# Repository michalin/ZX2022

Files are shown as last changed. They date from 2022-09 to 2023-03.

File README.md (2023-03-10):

# ZX 2022
Yet another homebuilt Z80 Computer, but this one works without any FPGAs or Microcontrollers, but components that were available at the time when the Z80 processor was state of the art. It can run historic CP/M programs like Multiplan, Wordstar and MBasic, as well as some games. This is a reminiscense to the Sinclair ZX81 computer. 
In contrast to its predecessor, the ZX2020, this one uses a 32 kilobyte EE Prom to reliably store the CP/M BDOS and BIOS. Furthermore a PS/2, or  PS/2 compatible USB keyboard can be connected. With an optional TMS99x8 based video card, a  TV or monitor can also be used. This repository contains gerber files for both the ZX2022 and the video  card. So it can now be easily replicated.

## Features
- Zilog Z80 processor @6MHz, higher clock rates might also work.
- 128 Kilobytes of static RAM, can be switched in banks of 32k
- 32 Kilobytes of EEprom
- 2 Serial UART ports 187.5 kBaud (Clock freqency/32):
  - Terminal emulation, (Putty works best)
  - File transfer. Files in a special folder on the PC show up as drive B>
- EEprom provides 15 Kilobytes of file memory (drive A>). CP/M executables are started automatically after reset or power on
- IDE (PATA) interface. Provides 4x16 Kilobyte organized as drives C>..F>
- CP/M 3.0
- 64-Pin connector for up to 6 Extension modules
- Optional graphics card with TMS99x8. 
    - 256x192 pixels and 15 colors
    - 32 Sprites (8x8, 16x16 or 32x32 upscaled)
    - NTSC (TMS9918) or PAL (TMS9928)
- Supports PS/2 or PS/2 compatible USB keyboards. New USB keyboards or wireless keyboards may NOT work.
- Now programmable in C using SDCC (Small Device C Compiler)

## To build the ZX 2022, do the following
- Wire the parts on a breadboard or prototype board according to the schematic. 
- OR: Make or order a PCB based on the gerber files `./Schematic/Mainboard/gerber-main.zip` (Recommended)
- Load the Arduino Sketch `loader/loader.ino` into an Arduino Mega
- Plug the Arduino Mega on the Bus connector, where it is marked on the silkscreen
- Connect the TxB and RxB pins of the DART with Pin 0 (TX0) and 1 (RX0) of your Arduino Mega
- Start a serial terminal emulation, for example "Putty", set 187500 Baud, 8 Bit, 1 Stopbit, no parity
- On Windows, run the tool `bin/loader.exe`. Click on "ROM Image" and select the file `CPM/rom.img`
- When a welcome message and the CP/M prompt "B>" appears on your terminal emulation, the ZX2020 is ready to use. If you have a PATA compatible hard drive connected, you need to format it under CP/M with the "mkdsk.com" tool before you can use it. Note that all data on the disk will be lost. 

## Using The Serial Disk Drive
Connect RX0 of the Arduino with TxB and TX0 with RxB of the ZX2022. 
It is not necessary to plug the Arduino into the pin header. Instead of an Arduino, a USB to serial converter may be used here as well. Select the serial port in the drop down menu and check the "Connect" check box to establish the serial connection. After a reset, the serial disk drive can be accessed as drive B>.

The folder [CPM/serdisk](./CPM/serdisk/) contains the CP/M programs in up to 16 user folders numbered from 0 to 15. If any of these files have changed, click the "Reload" Button to apply the changes. To access the files from CP/M, type `B`, followed by the user number 1-15 and a colon. For example `B5:` gives access to the files under [CPM/serdisk/5](./CPM/serdisk/5)

## Connecting a Hard Drive
IDE (PATA) hard drives can be connected through a 40-Pin connector. I recommend using a CompactFlash with a CF to IDE adapter. Best suitable are adapters that support power supply over pin 20 like this one: [https://amzn.to/3SFdIag](https://amzn.to/3SFdIag). call ´mkdsk.com´ on the serial disk drive B> to format the drive.

## The Autostart Feature
Clicking the `File` button in the loader app uploads an executable CP/M file (*.com) that is executed after each power-on or reboot. The loader app detects when there is a new version of this "autostart program" and restarts the ZX2022 with this new version. This function is particularly useful for writing new software.

## Connecting a PS/2 Keyboard
Connect a PS/2 Keyboard like shown below:

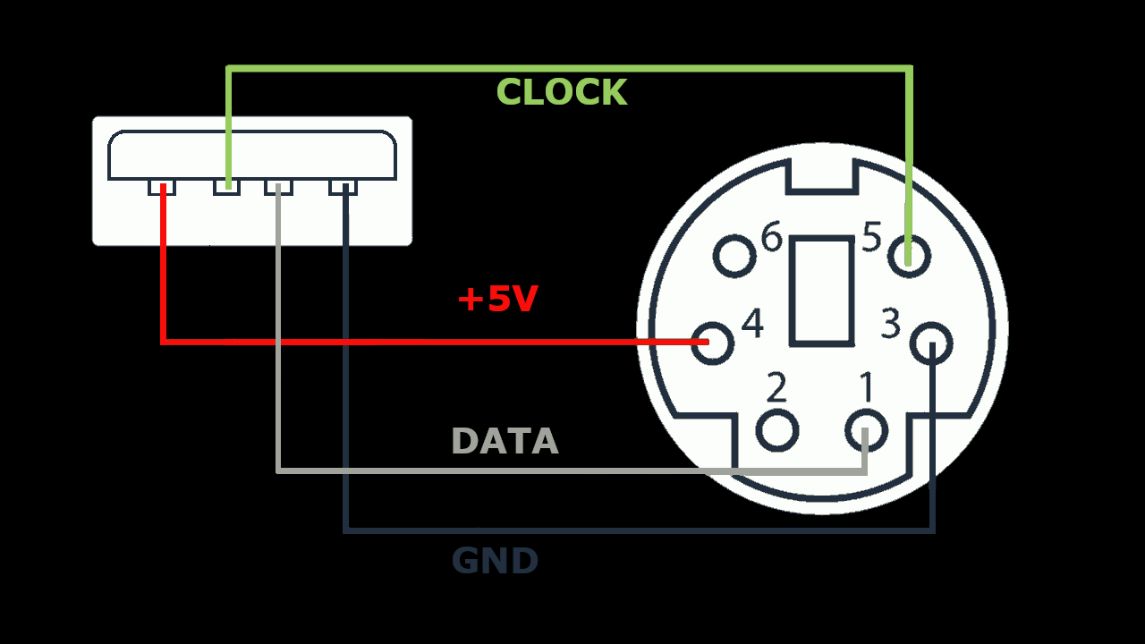
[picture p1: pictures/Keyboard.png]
PS/2 Keyboard Connection


## Connecting a USB Keyboard
USB Keyboards can also be connected if they support the PS/2 protocol. Most older keyboards do so, but newer or wireless keyboards often don't. These will not work.
I recommend to make an adapter cable from an USB extension cable as shown below:

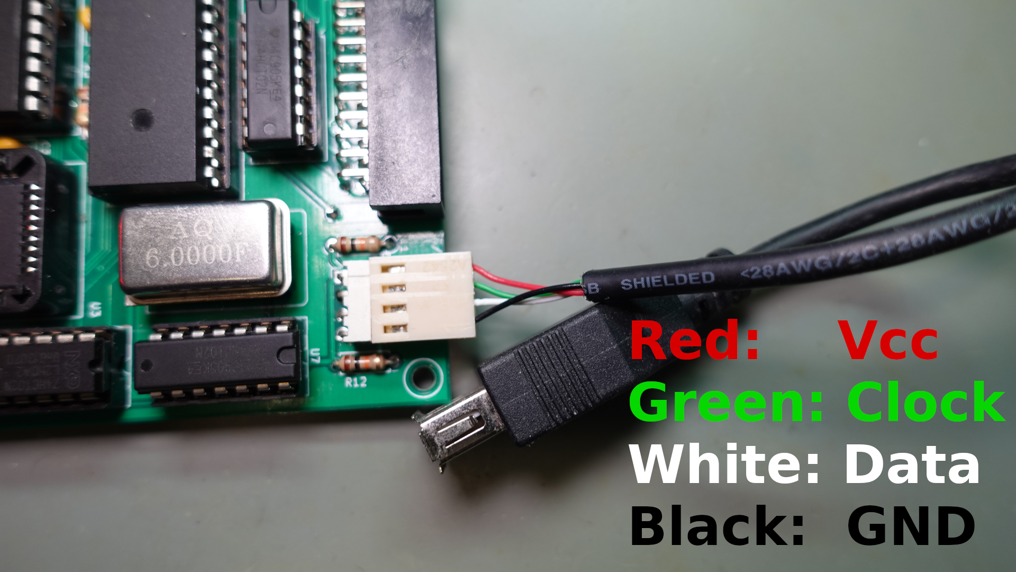
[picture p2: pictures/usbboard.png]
USB Keyboard Connection


## Changing the keyboard layout 
This is only necessary with PS/2 or USB keyboards. With terminal connections, the settings of the Windows-OS apply.
To change the keyboard layout, set the `KBLAYOUT` variable in the file [CPM/SYSCFG.LIB](./CPM/SYSCFG.LIB) either to `DE` or `EN` (default)
and [rebuild the CP/M rom image](CPM/README.md).

## Using With the TMS9918 Video Card
You find the schematic and gerber files in [Schematic/Video/](./Schematic/Video/). Set a jumper or solder a bridge at the position `IO2` on the pin header J3. This configures the card for IO addresses starting at 20h. This setting must match the `p$vdp` constant in [CPM/SYSCFG.LIB](./CPM/SYSCFG.LIB)

The TMS9918 can only display 40 columns, while terminals display 80 columns. This CP/M version is built for 80 columns, but it can be changed to 40 columns. To do this, open the file [gencpm.dat](./CPM/gencpm.dat), change the constant `PAGWID` to 28 (Which is 40 in hex) and [rebuild the CP/M rom image](CPM/README.md).

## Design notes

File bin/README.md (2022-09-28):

loader.exe: Windows-tool to upload the Rom image or autostart file. Also Serial file server.
rmac.exe: 8080 Macro Cross Assembler: https://github.com/Tbxxx/zxcc-windows
zmac.exe: Z-80 Macro Cross Assembler: http://48k.ca/zmac.html
drilink.exe: Linker: https://github.com/Tbxxx/zxcc-windows

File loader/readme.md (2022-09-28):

# Loader Sketch For Arduino
This is the Arduino Sketch that writes the CP/M Rom image `(rom.img)` directly into RAM and starts CP/M when finished. Afterwards it serves as serial-USB converter for the serial disk emulation.
## Todo
Open the sketch with Arduino-IDE or any other IDE with AVM support and select *`Tools->Board->"Arduino Mega or Mega 2560`*.

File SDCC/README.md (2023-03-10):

# Adaptions for SDCC (Small Device C compiler)

[SDCC](https://sdcc.sourceforge.net) is a cross compiler for Windows or Linux that can also generate Z80 code. It generates an Intel HEX file (*.ihx). Use [srec_cat](http://sourceforge.net/projects/srecord) to convert this to a binary file that can be uploaded to the ZX2022 by the loader app. [zx2022.c](zx2022.c) contains platform specific IO functions like printf and others, that are not implemented in the SDCC Z80 library. [worm.c](worm.c) is a simple worm/snake game that serves as an example.

### Compiling the example
To compile the "worm.c" example source file, type on the command line:  
`sdcc -mz80 --no-std-crt0 -I include -c worm.c -o source.rel`

If it is necessary to compile zx2022.c to get zx2022.rel, type:  
`sdcc -mz80 --no-std-crt0 -I include -c zx2022.c`

To link the *.rel files:  
`sdldz80 -nf zx2022.lk`

To convert the Intel Hex file "worm.ihx" to a CP/M executable:  
`srec_cat zx2022.ihx -intel -offset=-0x100 -o worm.com -binary`

For your convenience, you can call the makefile (GNU make utility required):  
`make src=worm`

For more information about complier options, refer to the documentation

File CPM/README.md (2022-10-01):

# Compiling CP/M 
This folder contains the system files, sources and some CP/M user programs in the directory [serdisk](./serdisk/). You only need to compile the source files (*.asm), if you want to make changes to the kernel, like changing the keyboard layout, for example. 
## Requirements: 
 - Windows command prompt or PowerShell
 - GNU make utility for Windows: [https://gnuwin32.sourceforge.net/packages/make.htm](https://gnuwin32.sourceforge.net/packages/make.htm)

## Todo:
- Add GNU make utiliy executable (make.exe) to your Path.
- Open a command shell and type "make"

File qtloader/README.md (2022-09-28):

# Source of loader.exe

This is the QT App that lets you upload the Rom image (rom.img) to your Z80 computer via the Arduino Mega. It also serves as serial "Fileserver". I recommend to use Qt 6.0.0 or higher to build the executable. I developed and tested all under Windows 10, but it might also work on other platforms that are supported by QT. I have never tested this, so I cannot tell whether it works.

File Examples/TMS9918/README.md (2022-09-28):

# TMS9918 Example
This example shows a Bitmap on the TMS9918

## Create Own Bitmaps
- Upload an image to the [MSX Screen Converter](https://msx.jannone.org/conv/)
- Select Conversion: "Screen2 (256x192)" and Palette: "MSX1 Colors" 
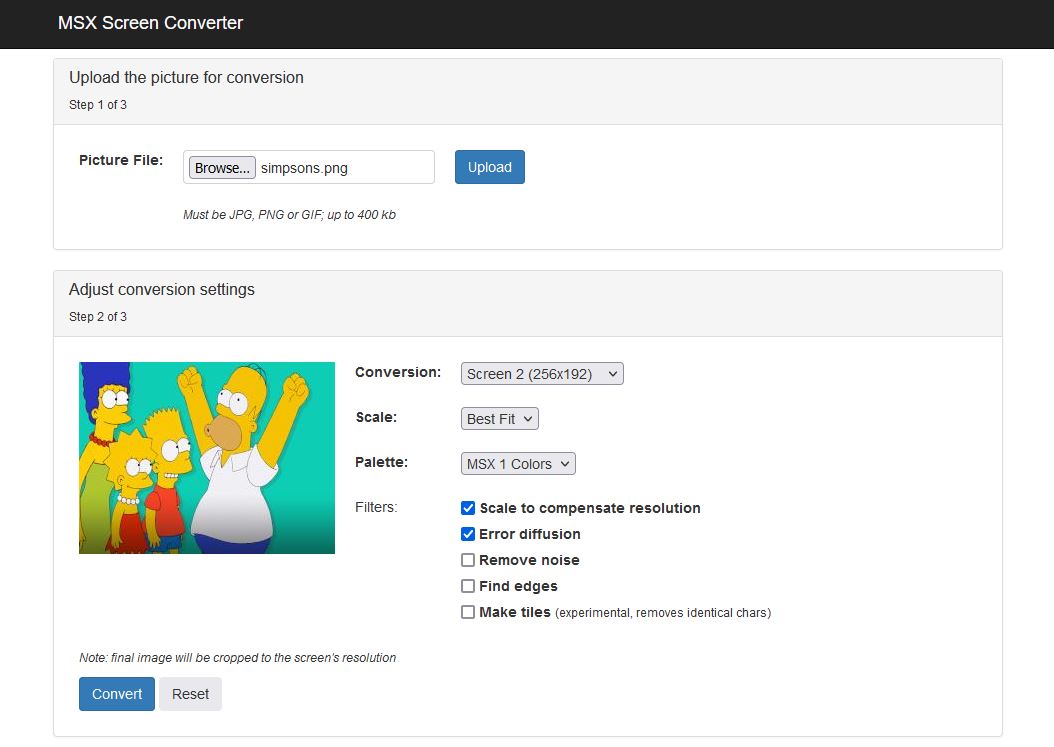
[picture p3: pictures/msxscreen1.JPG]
MSX Screen Converter
- click "Convert"   
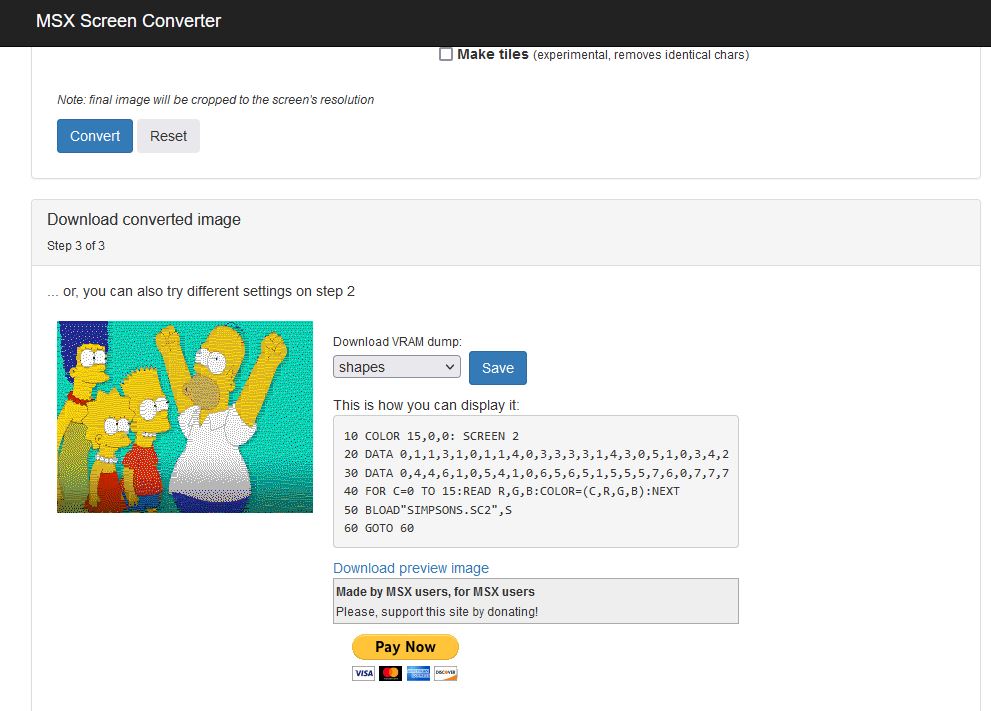
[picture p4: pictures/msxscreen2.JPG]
MSX Screen Converter
- Play with the conversion settings until it looks best 
  
- Download the VRAM dumps:
  - Shapes: Save as `.pat` file, i.e. `simpsons.pat` 
  - Attributes: Save as `.col` file, i.e. `simpsons.col`
- Change the filenames after the "incbin" directives at the end of [tms9918.asm](tms9918.asm)
- Type `make` to assemble

Congrats if you see this:
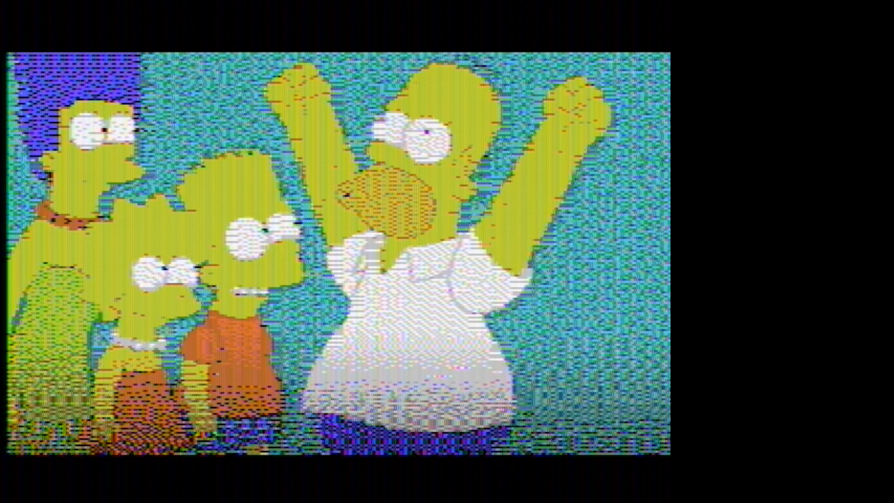
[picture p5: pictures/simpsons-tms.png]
Simpsons


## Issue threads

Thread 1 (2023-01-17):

Parts list or BOM

skspurling, 2023-01-17:
I may be missing something, but I don't see one.

skspurling, 2023-01-18:
Okay, I exported it from KiCad. Might be nice just to export the parts list CSV to the schematics directory or put the BoM list in the readme.

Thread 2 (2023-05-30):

Boot Issue - Some pointers would be much appreciated

danriches, 2023-05-30:
Hi,

I've had the pcb's made and I think the TMS9918's I bought are fake as it seems to kill the bus. I removed the video board and after connecting the Arduino Mega I loaded the rom.img into the board. I had several other issues so I then replaced the Z80 with a known working one then programmed the rom.img file again. Now it boots up and only shows a two line message and then seems to get stuck, the message is:
"ZX2020 CP/M 3.1. Have fun."
"Looking for hard drive... found."

Now the found message changes to not found if I remove my CF to IDE adapter so that seems to work. However I never get a booted ready prompt no matter what I do. Do you have any pointers as to what I should do? Do I need to recompile CP/M as I don't have the video board connected anymore?

I'm desperate to get this running as it'd be so much fun and I can use it as a platform to teach my boys some low level coding.

Thanks Doctor Volt and thanks for a great project that I'm certain works fine, it's just I must be doing something wrong!!

Thanks, Dan Riches

danriches, 2023-06-01:
I had two issues, the first was a dodgy SRAM chip and the second was that using the autorun function caused it to stop booting properly for some reason. Anyway it's all working now, I just need to find a compatible CF card as all mine either fail completely or fall over when using the pip c:=*.* command with "ERROR: CLOSE FILE  - C:COPYSYS.$$$". I'll try copying one file at a time and see if that works...

michalin, 2023-06-01:
Did you format the CF card with the "mkdsk.com" utility? This writes the needed files to the CF card. You can watch the video from 7:03 for instructions: https://youtu.be/lTf1Y5tybfo?t=423

Closed 2023-06-02.

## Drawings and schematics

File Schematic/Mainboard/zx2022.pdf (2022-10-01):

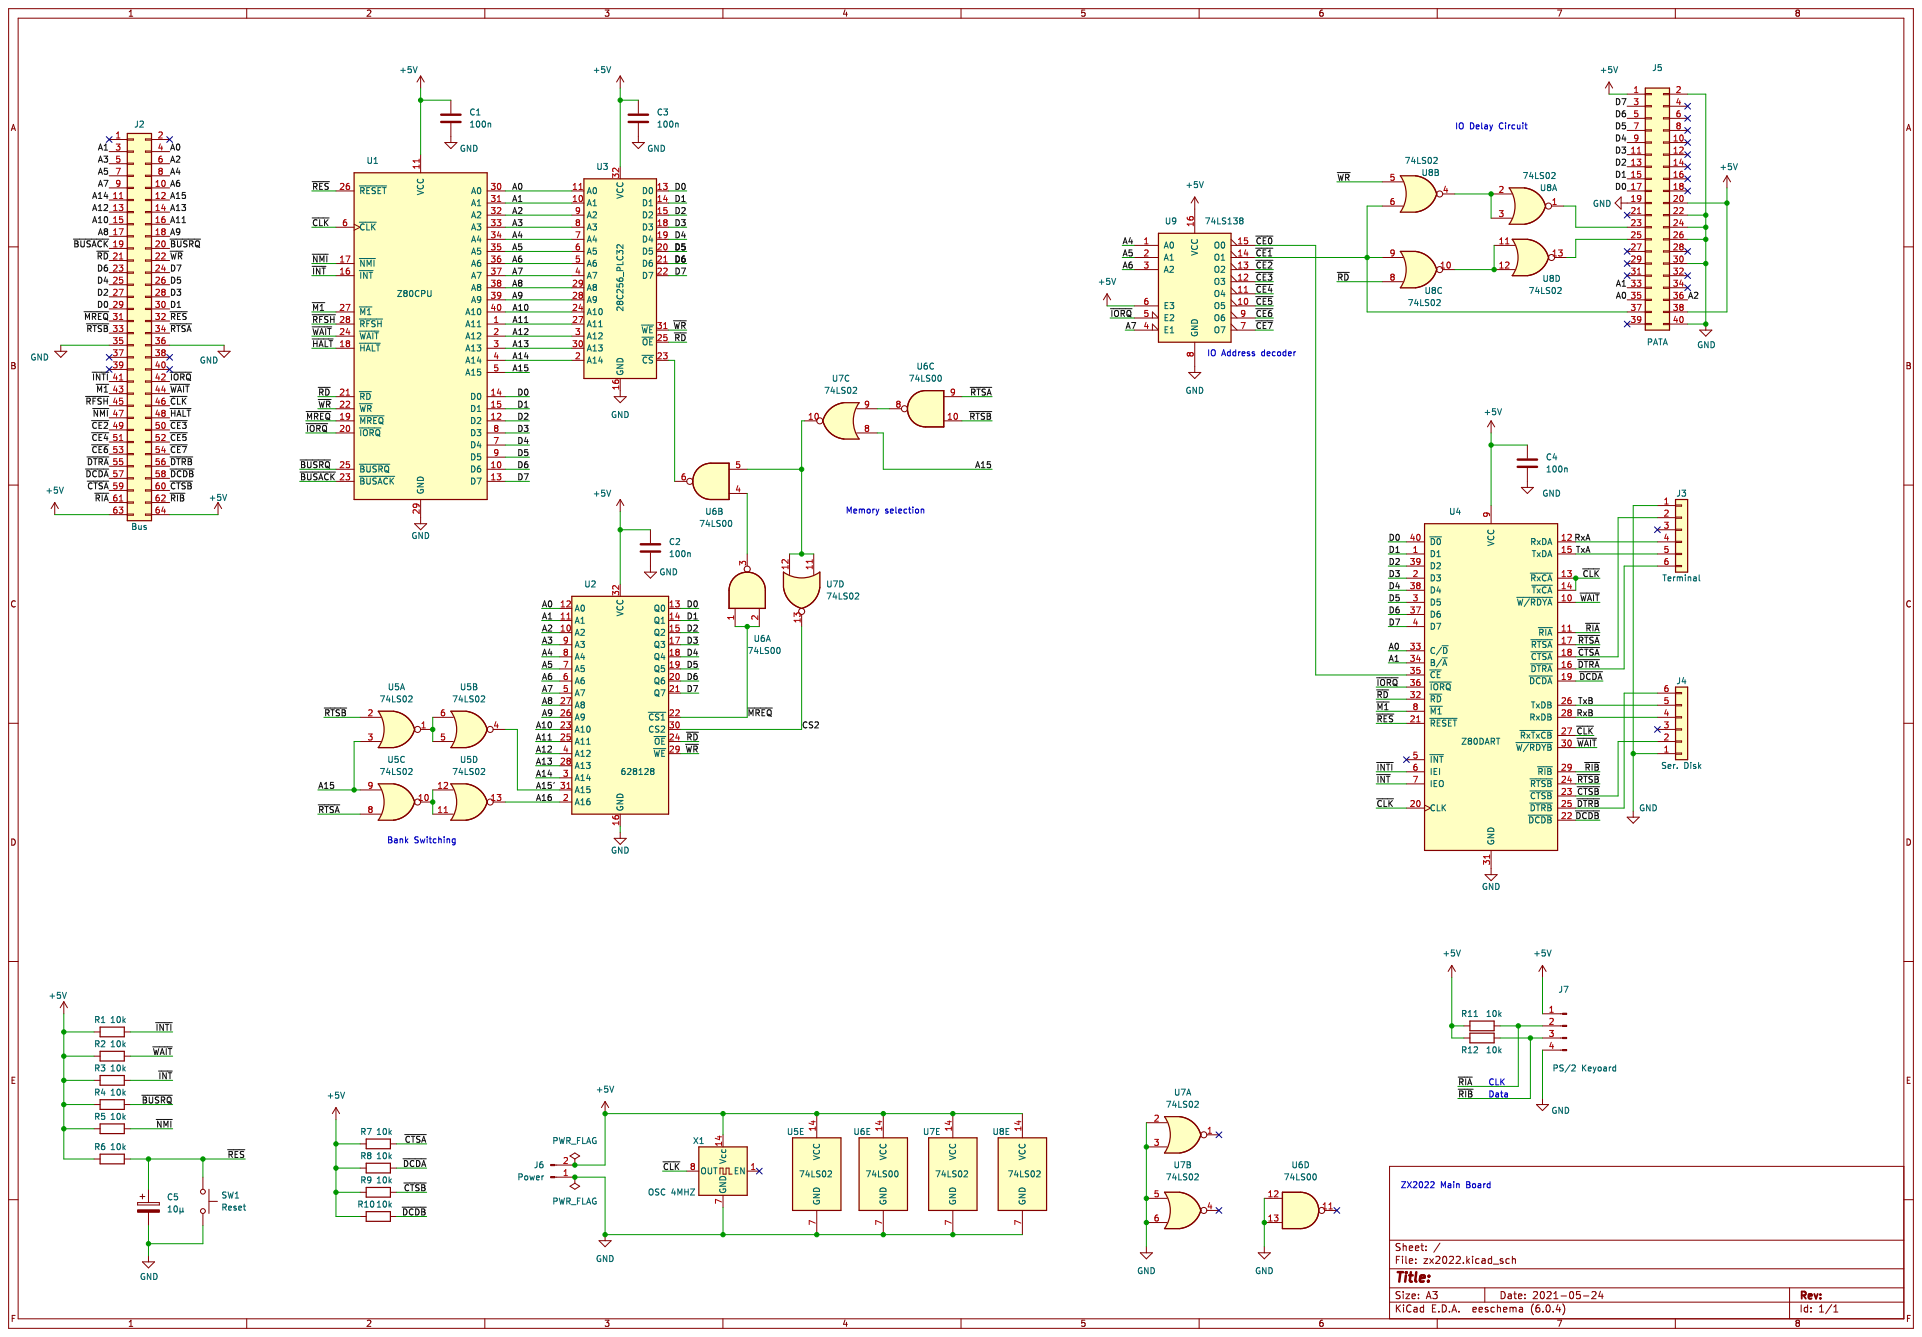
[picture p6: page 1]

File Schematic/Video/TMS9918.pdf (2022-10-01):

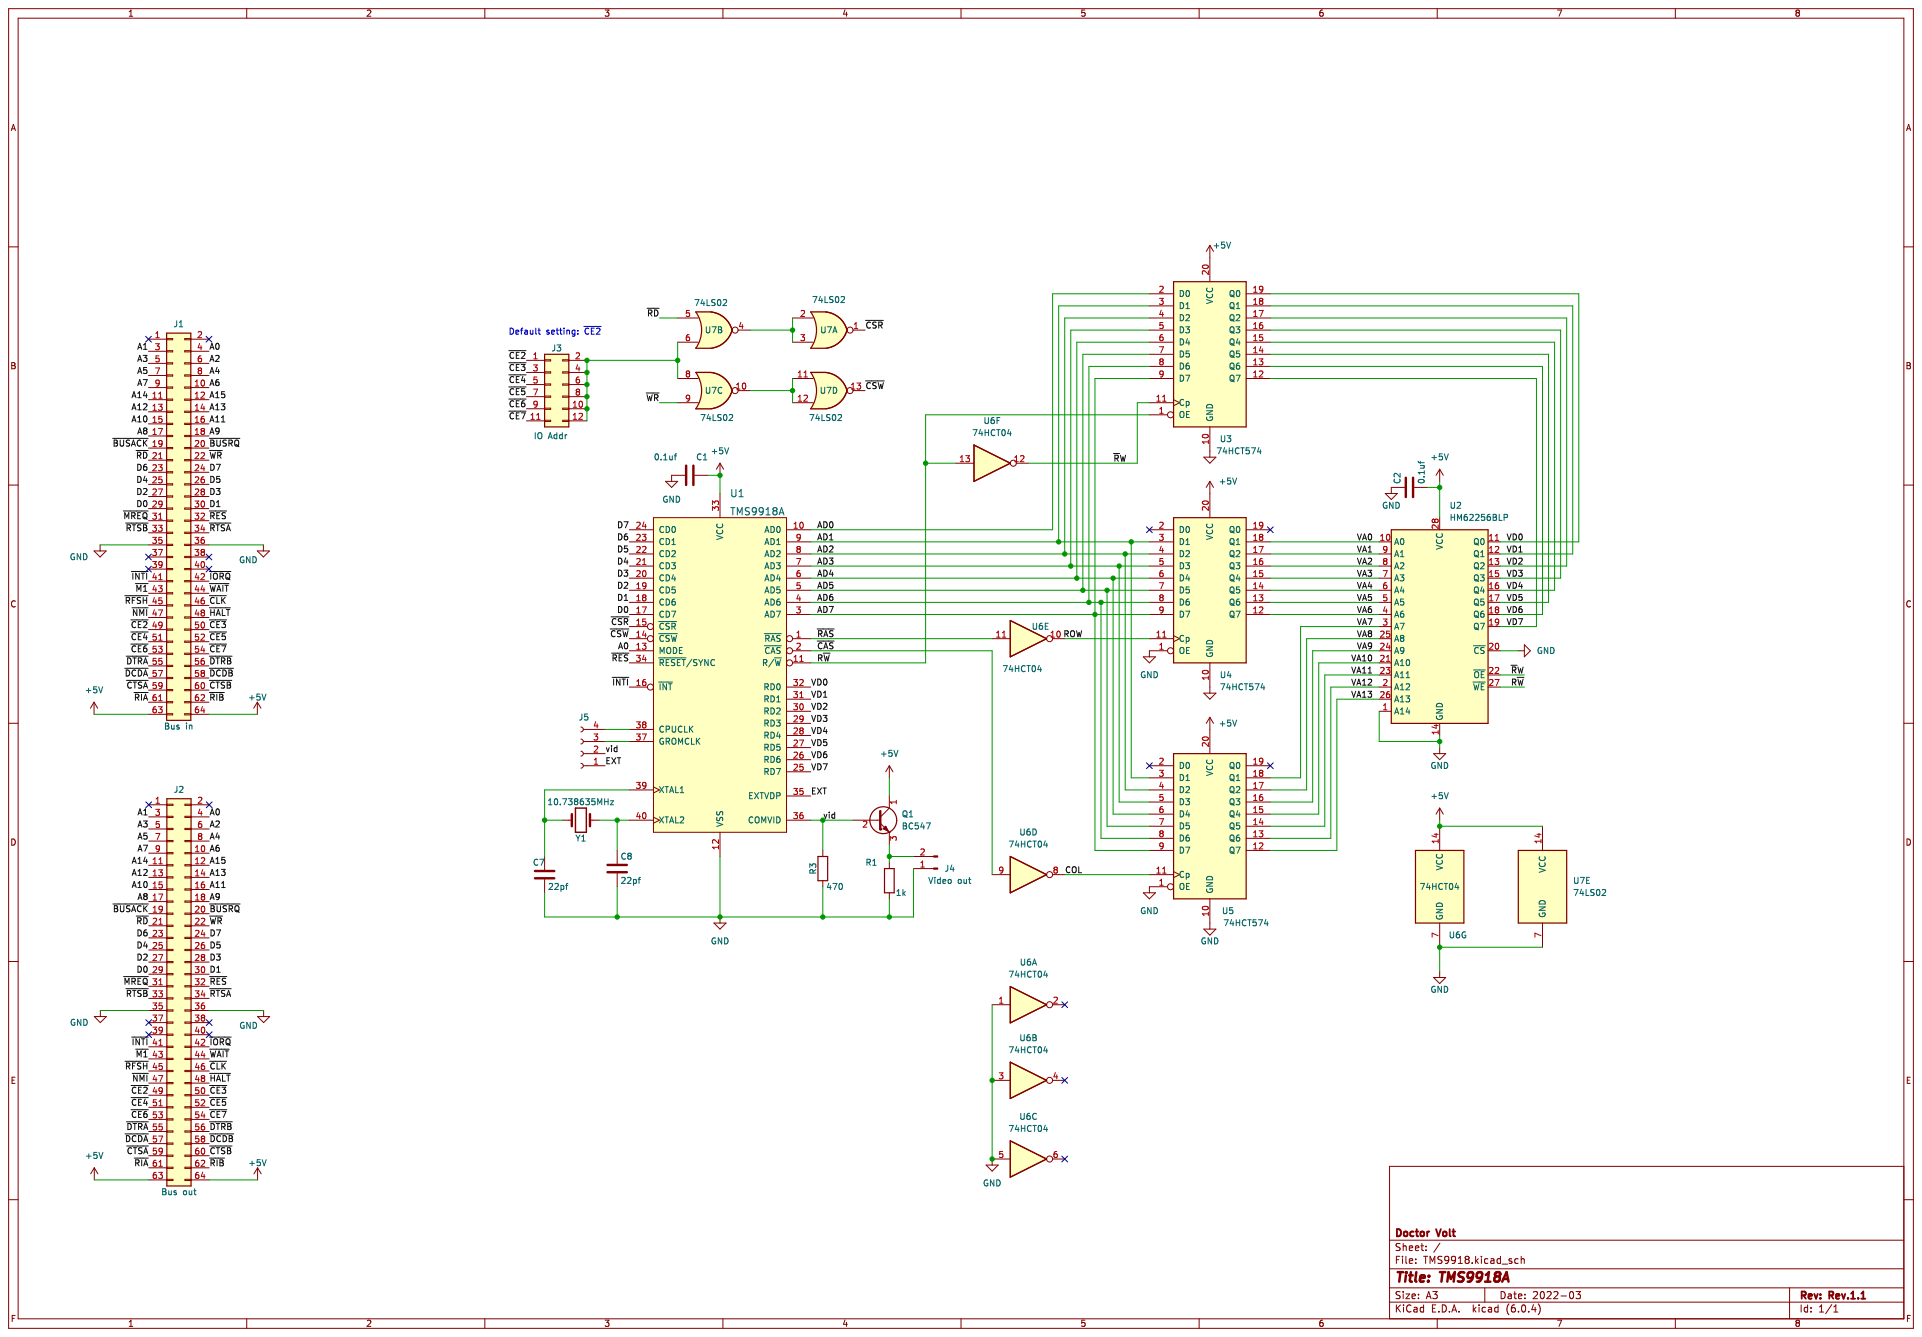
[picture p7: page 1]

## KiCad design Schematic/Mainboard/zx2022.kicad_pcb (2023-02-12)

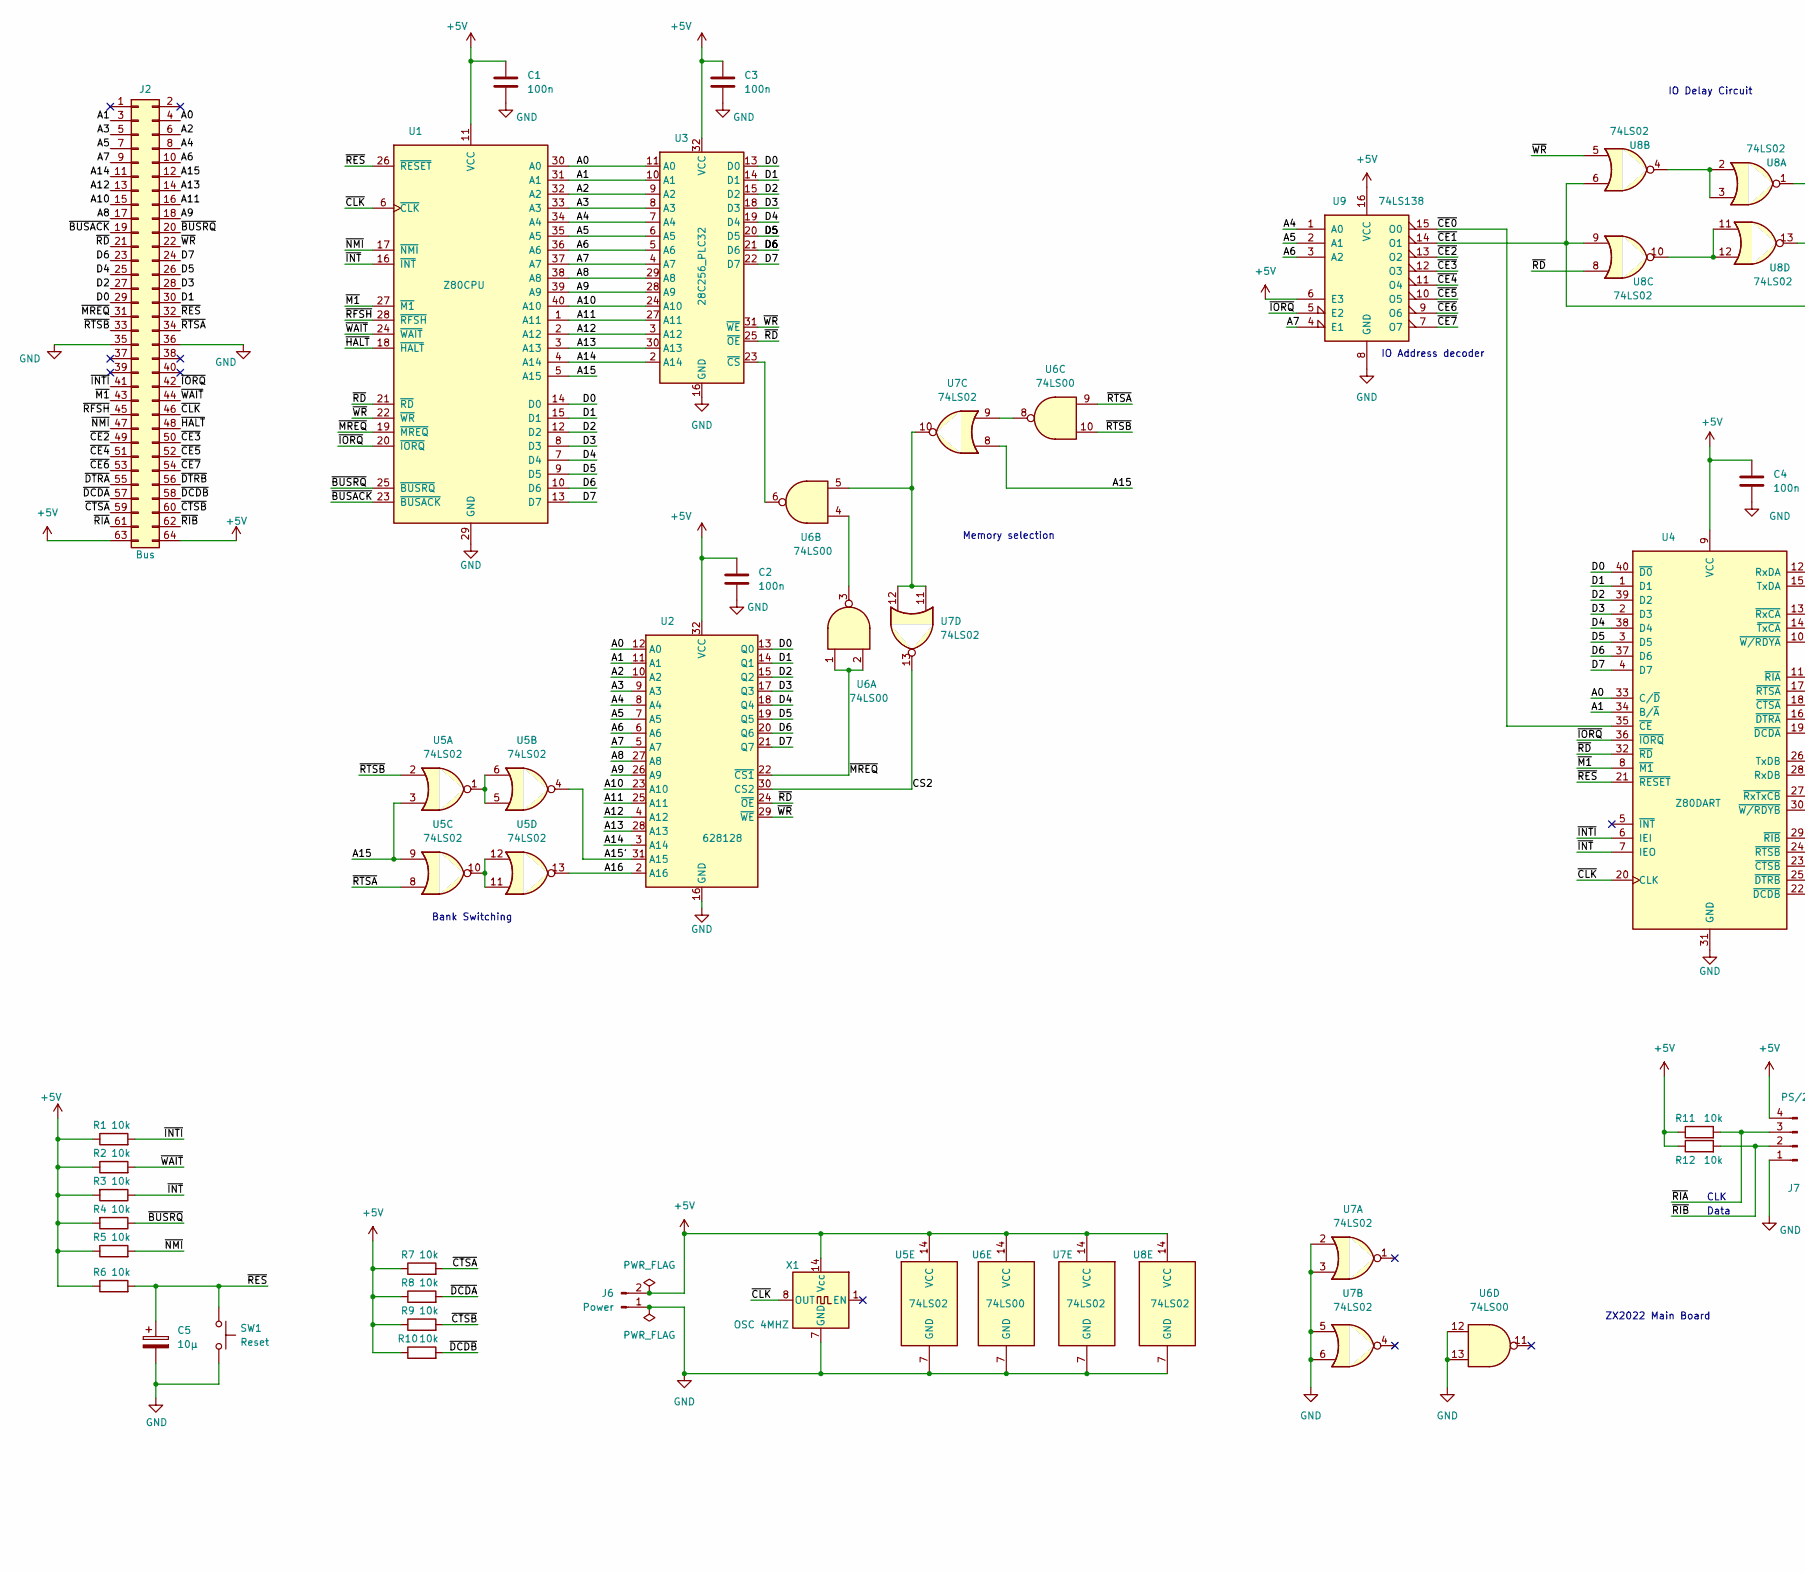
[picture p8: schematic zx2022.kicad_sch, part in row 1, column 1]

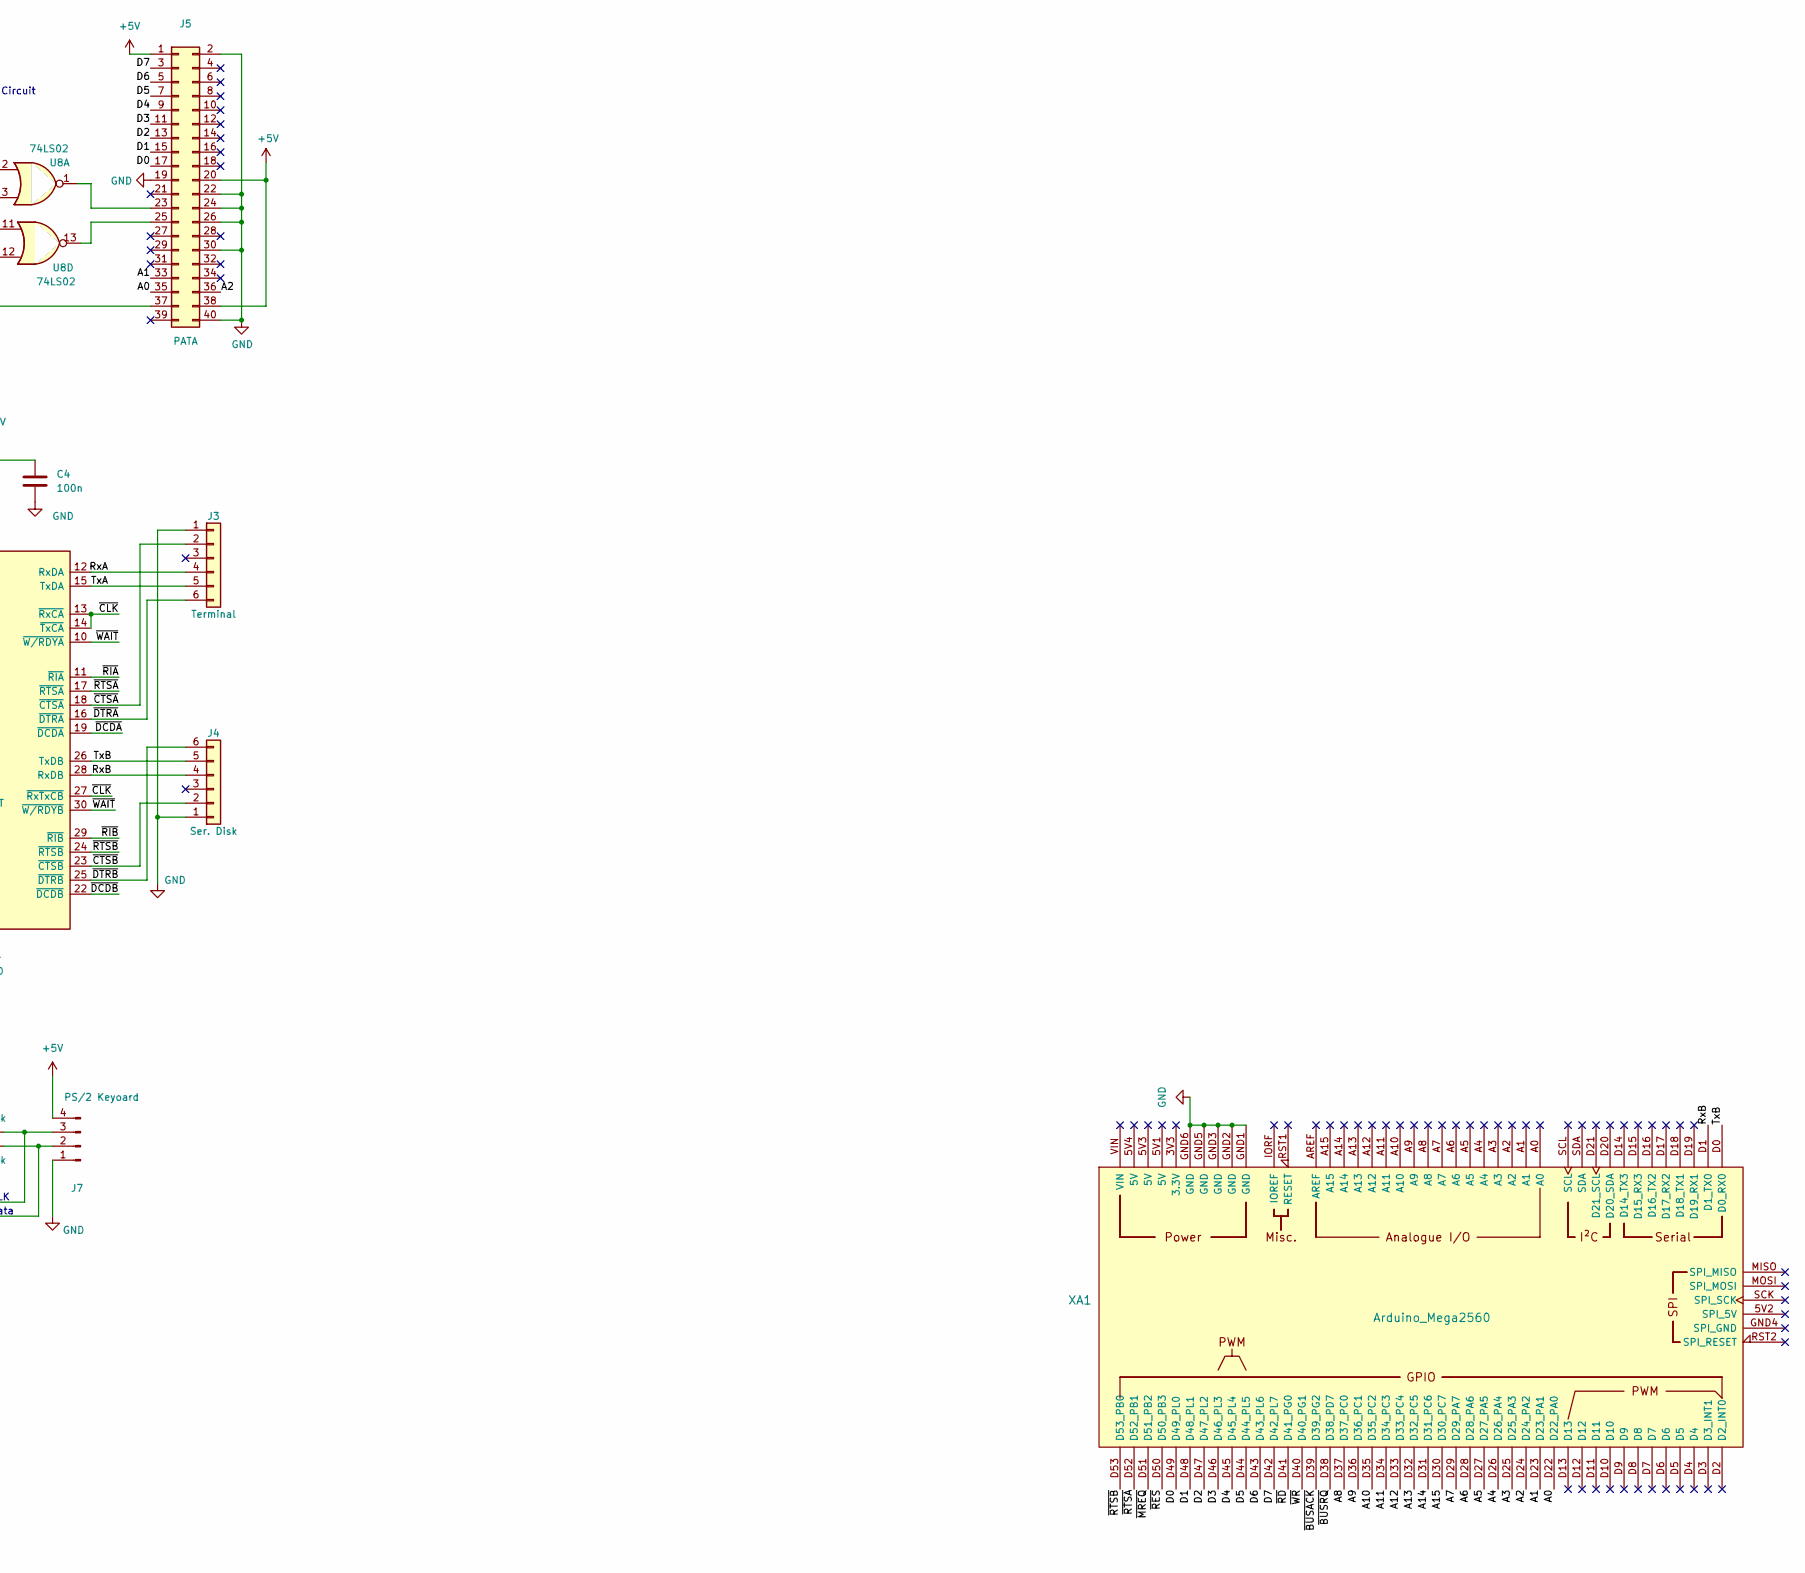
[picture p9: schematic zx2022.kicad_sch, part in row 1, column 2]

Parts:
C1, C2, C3, C4: 100n; C_Disc_D5.0mm_W2.5mm_P2.50mm
C5: 10µ; CP_Radial_D5.0mm_P2.50mm
J2: Bus; PinHeader_2x32_P2.54mm_Vertical
J3: Terminal; PinSocket_1x06_P2.54mm_Vertical
J4: Ser. Disk; PinSocket_1x06_P2.54mm_Vertical
J5: PATA; BoxConn_2x20_P2.54mm_Horizontal
J6: Power; PinHeader_1x02_P2.54mm_Horizontal
J7: PS/2 Keyoard; PinHeader_1x04_P2.54mm_Horizontal
R1, R2, R3, R4, R5, R6, R7, R8, R9, R10, R11, R12: 10k; R_Axial_DIN0207_L6.3mm_D2.5mm_P7.62mm_Horizontal
SW1: Reset; SW_PUSH_6mm
U1: Z80CPU; DIP-40_W15.24mm_Socket
U2: 628128; DIP-32_W15.24mm_Socket
U3: 28C256_PLC32; PLCC-32_THT-Socket
U4: Z80DART; DIP-40_W15.24mm_Socket
U5, U7, U8: 74LS02; DIP-14_W7.62mm_Socket
U6: 74LS00; DIP-14_W7.62mm_Socket
U9: 74LS138; DIP-16_W7.62mm_Socket
X1: OSC 4MHZ; Oscillator_DIP-14
XA1: Arduino_Mega2560; Arduino_Mega2560_Shield

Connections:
+5V: C1.1, C2.1, C3.1, C4.1, J2.63, J2.64, J5.1, J5.20, J5.38, J6.2, J7.4, R1.1, R2.1, R3.2, R4.2, R5.1, R6.1, R7.1, R8.1, R9.1, R10.1, R11.1, R12.1, U1.11 (VCC), U2.32 (VCC), U3.32 (VCC), U4.9 (VCC), U5.14 (VCC), U6.14 (VCC), U7.14 (VCC), U8.14 (VCC), U9.6 (E3), U9.16 (VCC), X1.14 (Vcc)
/A0: J2.4, J5.35, U1.30 (A0), U2.12 (A0), U3.11 (A0), U4.33 (C/~D), XA1.D22 (D22_PA0)
/A1: J2.3, J5.33, U1.31 (A1), U2.11 (A1), U3.10 (A1), U4.34 (B/~A), XA1.D23 (D23_PA1)
/A2: J2.6, J5.36, U1.32 (A2), U2.10 (A2), U3.9 (A2), XA1.D24 (D24_PA2)
/A3: J2.5, U1.33 (A3), U2.9 (A3), U3.8 (A3), XA1.D25 (D25_PA3)
/A4: J2.8, U1.34 (A4), U2.8 (A4), U3.7 (A4), U9.1 (A0), XA1.D26 (D26_PA4)
/A5: J2.7, U1.35 (A5), U2.7 (A5), U3.6 (A5), U9.2 (A1), XA1.D27 (D27_PA5)
/A6: J2.10, U1.36 (A6), U2.6 (A6), U3.5 (A6), U9.3 (A2), XA1.D28 (D28_PA6)
/A7: J2.9, U1.37 (A7), U2.5 (A7), U3.4 (A7), U9.4 (E1), XA1.D29 (D29_PA7)
/A8: J2.17, U1.38 (A8), U2.27 (A8), U3.29 (A8), XA1.D37 (D37_PC0)
/A9: J2.18, U1.39 (A9), U2.26 (A9), U3.28 (A9), XA1.D36 (D36_PC1)
/A10: J2.15, U1.40 (A10), U2.23 (A10), U3.24 (A10), XA1.D35 (D35_PC2)
/A11: J2.16, U1.1 (A11), U2.25 (A11), U3.27 (A11), XA1.D34 (D34_PC3)
/A12: J2.13, U1.2 (A12), U2.4 (A12), U3.3 (A12), XA1.D33 (D33_PC4)
/A13: J2.14, U1.3 (A13), U2.28 (A13), U3.30 (A13), XA1.D32 (D32_PC5)
/A14: J2.11, U1.4 (A14), U2.3 (A14), U3.2 (A14), XA1.D31 (D31_PC6)
/A15: J2.12, U1.5 (A15), U5.3, U5.9, U7.8, XA1.D30 (D30_PC7)
/A15': U2.31 (A15), U5.4
/A16: U2.2 (A16), U5.13
/CS2: U2.30 (CS2), U7.13
/D0: J2.29, J5.17, U1.14 (D0), U2.13 (Q0), U3.13 (D0), U4.40 (~D0), XA1.D49 (D49_PL0)
/D1: J2.30, J5.15, U1.15 (D1), U2.14 (Q1), U3.14 (D1), U4.1 (D1), XA1.D48 (D48_PL1)
/D2: J2.27, J5.13, U1.12 (D2), U2.15 (Q2), U3.15 (D2), U4.39 (D2), XA1.D47 (D47_PL2)
/D3: J2.28, J5.11, U1.8 (D3), U2.17 (Q3), U3.18 (D3), U4.2 (D3), XA1.D46 (D46_PL3)
/D4: J2.25, J5.9, U1.7 (D4), U2.18 (Q4), U3.19 (D4), U4.38 (D4), XA1.D45 (D45_PL4)
/D5: J2.26, J5.7, U1.9 (D5), U2.19 (Q5), U3.20 (D5), U4.3 (D5), XA1.D44 (D44_PL5)
/D6: J2.23, J5.5, U1.10 (D6), U2.20 (Q6), U3.21 (D6), U4.37 (D6), XA1.D43 (D43_PL6)
/D7: J2.24, J5.3, U1.13 (D7), U2.21 (Q7), U3.22 (D7), U4.4 (D7), XA1.D42 (D42_PL7)
/RxA: J3.4, U4.12 (RxDA)
/RxB: J4.4, U4.28 (RxDB), XA1.D1 (D1_TX0)
/TxA: J3.5, U4.15 (TxDA)
/TxB: J4.5, U4.26 (TxDB), XA1.D0 (D0_RX0)
/~BUSACK: J2.19, U1.23 (~BUSACK), XA1.D39 (D39_PG2)
/~BUSRQ: J2.20, R4.1, U1.25 (~BUSRQ), XA1.D38 (D38_PD7)
/~CE0: U4.35 (~CE), U9.15 (O0)
/~CE1: J5.37, U8.6, U8.9, U9.14 (O1)
/~CE2: J2.49, U9.13 (O2)
/~CE3: J2.50, U9.12 (O3)
/~CE4: J2.51, U9.11 (O4)
/~CE5: J2.52, U9.10 (O5)
/~CE6: J2.53, U9.9 (O6)
/~CE7: J2.54, U9.7 (O7)
/~CLK: J2.46, U1.6 (~CLK), U4.13 (~RxCA), U4.14 (~TxCA), U4.20 (CLK), U4.27 (~RxTxCB), X1.8 (OUT)
/~CTSA: J2.59, J3.2, R7.2, U4.18 (~CTSA)
/~CTSB: J2.60, J4.2, R9.2, U4.23 (~CTSB)
/~DCDA: J2.57, R8.2, U4.19 (~DCDA)
/~DCDB: J2.58, R10.2, U4.22 (~DCDB)
/~DTRA: J2.55, J3.6, U4.16 (~DTRA)
/~DTRB: J2.56, J4.6, U4.25 (~DTRB)
/~HALT: J2.48, U1.18 (~HALT)
/~INTI: J2.41, R1.2, U4.6 (IEI)
/~INT: R3.1, U1.16 (~INT), U4.7 (IEO)
/~IORQ: J2.42, U1.20 (~IORQ), U4.36 (~IORQ), U9.5 (E2)
/~M1: J2.43, U1.27 (~M1), U4.8 (~M1)
/~MREQ: J2.31, U1.19 (~MREQ), U2.22 (~CS1), U6.1, U6.2, XA1.D51 (D51_PB2)
/~NMI: J2.47, R5.2, U1.17 (~NMI)
/~RD: J2.21, U1.21 (~RD), U2.24 (~OE), U3.25 (~OE), U4.32 (~RD), U8.8, XA1.D41 (D41_PG0)
/~RES: C5.1, J2.32, R6.2, SW1.1, U1.26 (~RESET), U4.21 (~RESET), XA1.D50 (D50_PB3)
/~RFSH: J2.45, U1.28 (~RFSH)
/~RIA: J2.61, J7.3, R11.2, U4.11 (~RIA)
/~RIB: J2.62, J7.2, R12.2, U4.29 (~RIB)
/~RTSA: J2.34, U4.17 (~RTSA), U5.8, U6.9, XA1.D52 (D52_PB1)
/~RTSB: J2.33, U4.24 (~RTSB), U5.2, U6.10, XA1.D53 (D53_PB0)
/~WAIT: J2.44, R2.2, U1.24 (~WAIT), U4.10 (~W/RDYA), U4.30 (~W/RDYB)
/~WR: J2.22, U1.22 (~WR), U2.29 (~WE), U3.31 (~WE), U8.5, XA1.D40 (D40_PG1)
GND: C1.2, C2.2, C3.2, C4.2, C5.2, J2.35, J2.36, J3.1, J4.1, J5.2, J5.19, J5.22, J5.24, J5.26, J5.30, J5.40, J6.1, J7.1, SW1.2, U1.29 (GND), U2.16 (GND), U3.16 (GND), U4.31 (GND), U5.7 (GND), U6.7 (GND), U6.12, U6.13, U7.2, U7.3, U7.5, U7.6, U7.7 (GND), U8.7 (GND), U9.8 (GND), X1.7 (GND), XA1.GND1 (GND), XA1.GND2 (GND), XA1.GND3 (GND), XA1.GND5 (GND), XA1.GND6 (GND)
unnamed: J5.23, U8.1
unnamed: J5.25, U8.13
unnamed: U3.23 (~CS), U6.6
unnamed: U5.1, U5.5, U5.6
unnamed: U5.10, U5.11, U5.12
unnamed: U6.3, U6.4
unnamed: U6.5, U7.10, U7.11, U7.12
unnamed: U6.8, U7.9
unnamed: U8.2, U8.3, U8.4
unnamed: U8.10, U8.11, U8.12

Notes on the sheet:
Bank Switching
IO Address decoder
CLK
ZX2022 Main Board
IO Delay Circuit
Memory selection
Data

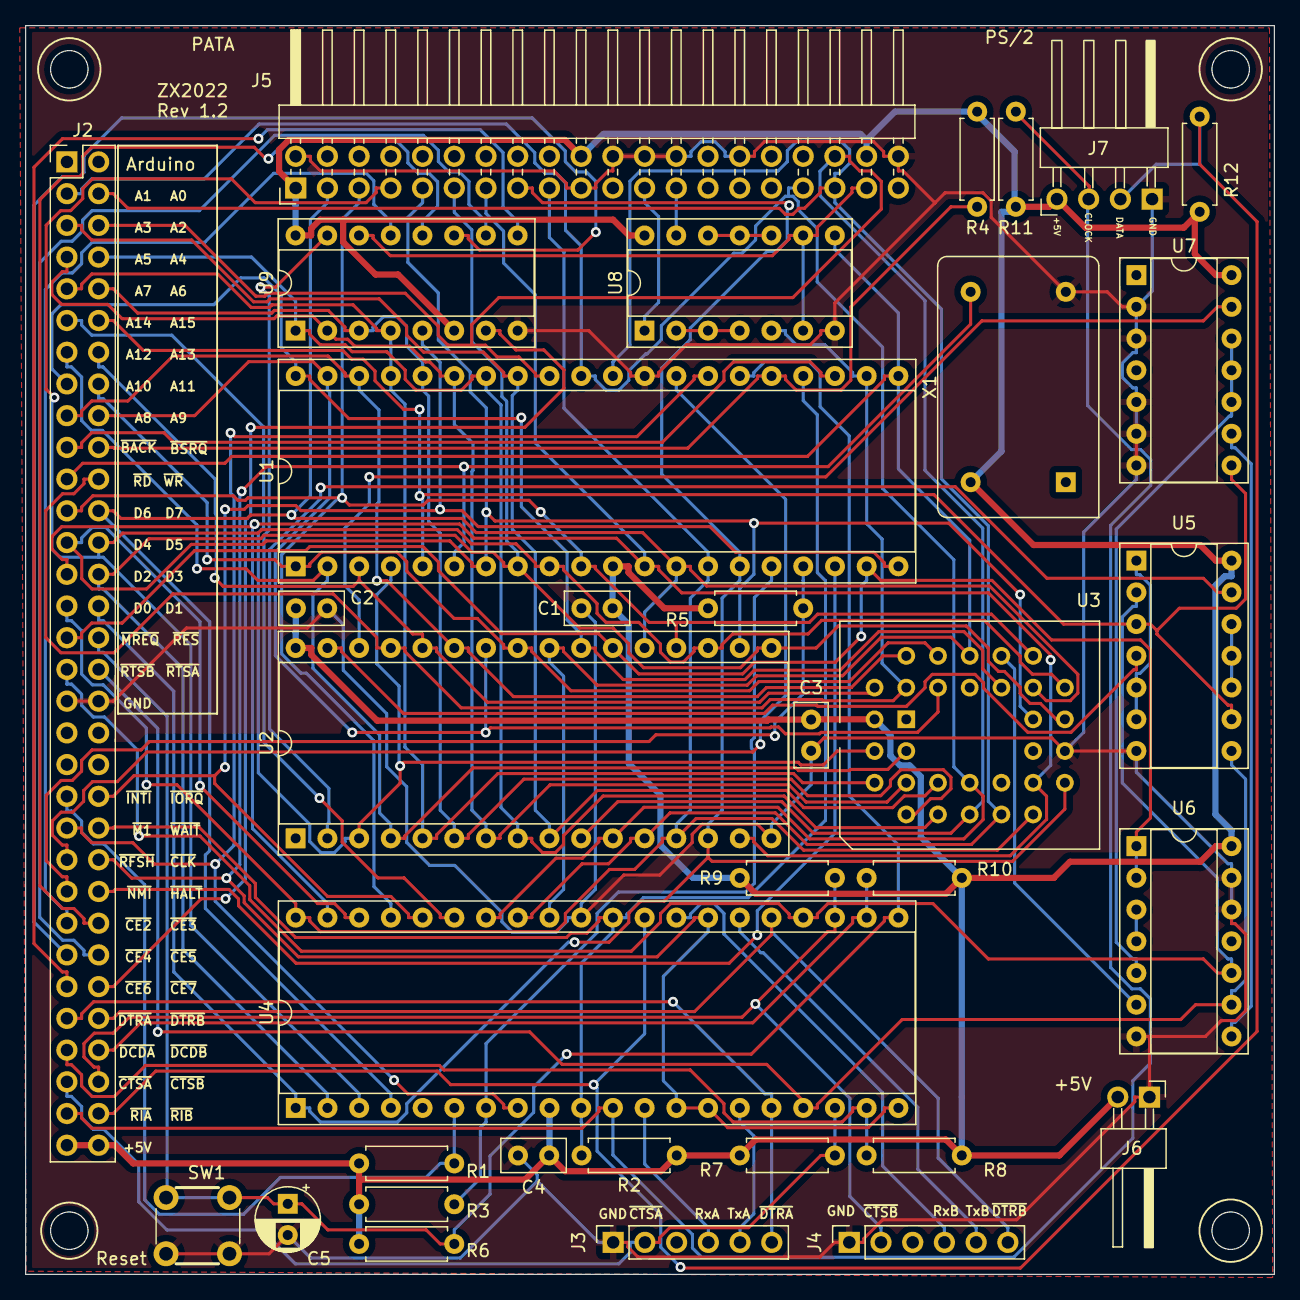
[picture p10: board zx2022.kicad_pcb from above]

Board: 2 copper layers, 100.0 x 100.0 mm, 34 parts (0 on the bottom side), 76 nets.

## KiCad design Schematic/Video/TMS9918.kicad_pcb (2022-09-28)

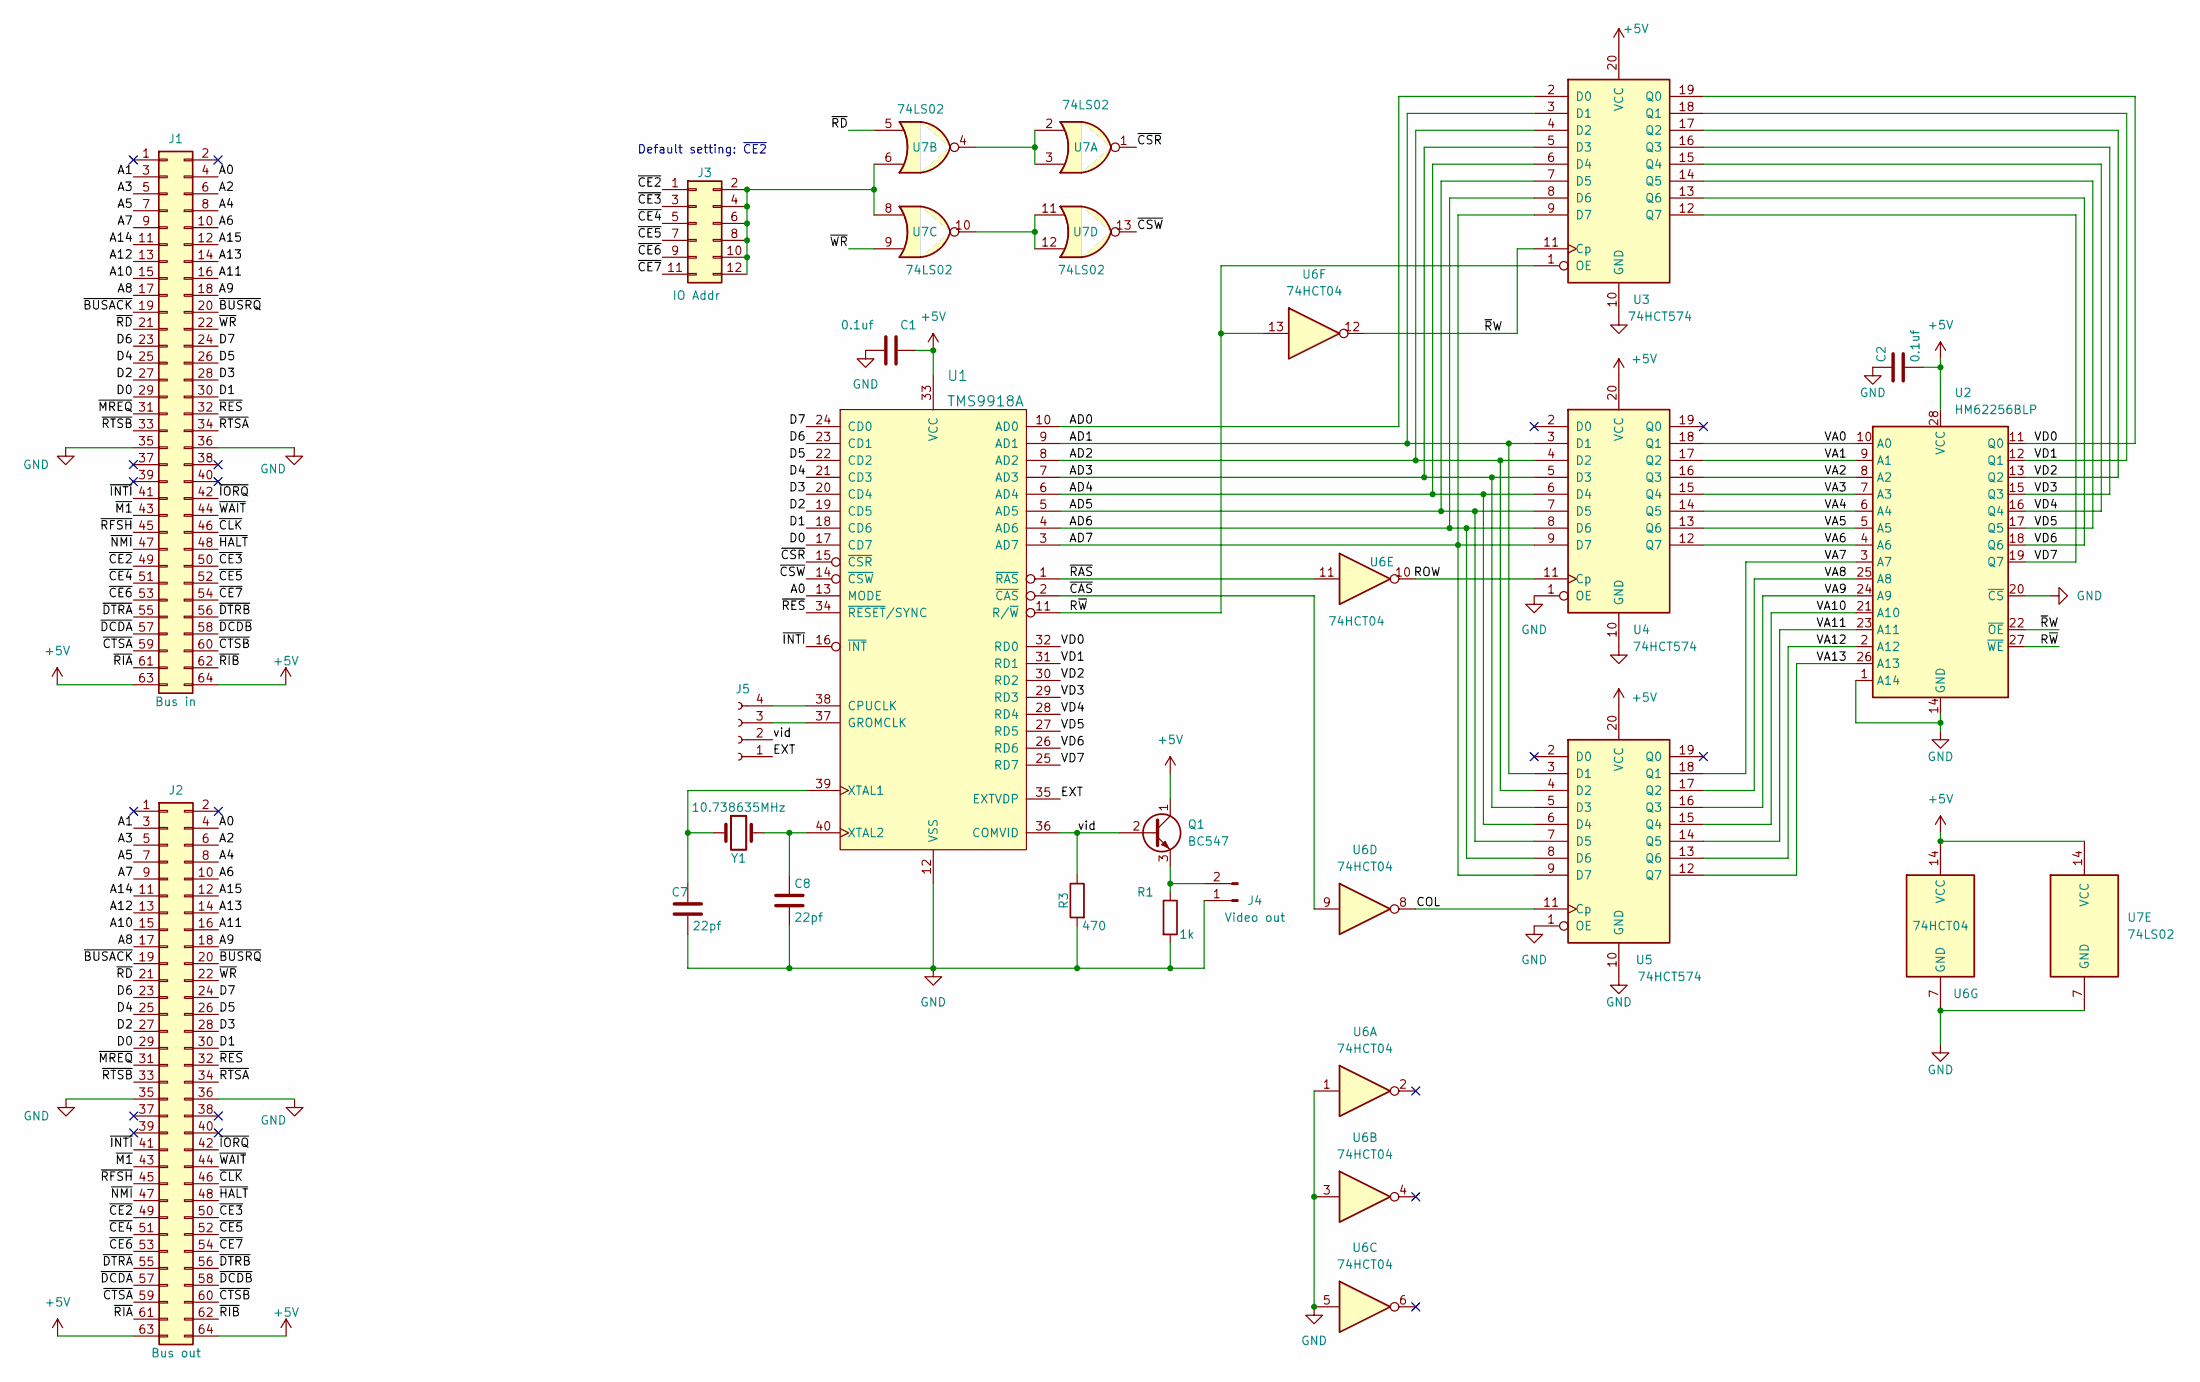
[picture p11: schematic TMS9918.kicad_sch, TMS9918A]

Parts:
C1, C2: 0.1uf; C_Disc_D3.0mm_W1.6mm_P2.50mm
C7, C8: 22pf; C_Disc_D3.0mm_W1.6mm_P2.50mm
J1: Bus in; PinHeader_2x32_P2.54mm_Vertical
J2: Bus out; PinHeader_2x32_P2.54mm_Vertical
J3: IO Addr; PinHeader_2x06_P2.54mm_Vertical
J4: Video out; PinHeader_1x02_P2.54mm_Horizontal
J5: Conn_01x04_Female; PinHeader_1x04_P2.54mm_Vertical
Q1: BC547; TO-92_Inline
R1: 1k; R_Axial_DIN0207_L6.3mm_D2.5mm_P7.62mm_Horizontal
R3: 470; R_Axial_DIN0207_L6.3mm_D2.5mm_P7.62mm_Horizontal
U1: TMS9918A; DIP-40_W15.24mm_Socket
U2: HM62256BLP; DIP-28_W15.24mm
U3, U4, U5: 74HCT574; DIP-20_W7.62mm_Socket
U6: 74HCT04; DIP-14_W7.62mm_Socket
U7: 74LS02; DIP-14_W7.62mm_Socket
Y1: 10.738635MHz; Crystal_HC49-4H_Vertical

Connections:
+5V: C1.1, C2.2, J1.63, J1.64, J2.63, J2.64, Q1.1 (C), U1.33 (VCC), U2.28 (VCC), U3.20 (VCC), U4.20 (VCC), U5.20 (VCC), U6.14 (VCC), U7.14 (VCC)
/A0: J1.4, J2.4, U1.13 (MODE)
/A1: J1.3, J2.3
/A2: J1.6, J2.6
/A3: J1.5, J2.5
/A4: J1.8, J2.8
/A5: J1.7, J2.7
/A6: J1.10, J2.10
/A7: J1.9, J2.9
/A8: J1.17, J2.17
/A9: J1.18, J2.18
/A10: J1.15, J2.15
/A11: J1.16, J2.16
/A12: J1.13, J2.13
/A13: J1.14, J2.14
/A14: J1.11, J2.11
/A15: J1.12, J2.12
/AD0: U1.10 (AD0), U3.2 (D0)
/AD1: U1.9 (AD1), U3.3 (D1), U4.3 (D1), U5.3 (D1)
/AD2: U1.8 (AD2), U3.4 (D2), U4.4 (D2), U5.4 (D2)
/AD3: U1.7 (AD3), U3.5 (D3), U4.5 (D3), U5.5 (D3)
/AD4: U1.6 (AD4), U3.6 (D4), U4.6 (D4), U5.6 (D4)
/AD5: U1.5 (AD5), U3.7 (D5), U4.7 (D5), U5.7 (D5)
/AD6: U1.4 (AD6), U3.8 (D6), U4.8 (D6), U5.8 (D6)
/AD7: U1.3 (AD7), U3.9 (D7), U4.9 (D7), U5.9 (D7)
/COL: U5.11 (Cp), U6.8
/D0: J1.29, J2.29, U1.17 (CD7)
/D1: J1.30, J2.30, U1.18 (CD6)
/D2: J1.27, J2.27, U1.19 (CD5)
/D3: J1.28, J2.28, U1.20 (CD4)
/D4: J1.25, J2.25, U1.21 (CD3)
/D5: J1.26, J2.26, U1.22 (CD2)
/D6: J1.23, J2.23, U1.23 (CD1)
/D7: J1.24, J2.24, U1.24 (CD0)
/EXT: J5.1, U1.35 (EXTVDP)
/ROW: U4.11 (Cp), U6.10
/R~W: U1.11 (R/~W), U2.27 (~WE), U3.1 (OE), U6.13
/VA0: U2.10 (A0), U4.18 (Q1)
/VA1: U2.9 (A1), U4.17 (Q2)
/VA2: U2.8 (A2), U4.16 (Q3)
/VA3: U2.7 (A3), U4.15 (Q4)
/VA4: U2.6 (A4), U4.14 (Q5)
/VA5: U2.5 (A5), U4.13 (Q6)
/VA6: U2.4 (A6), U4.12 (Q7)
/VA7: U2.3 (A7), U5.18 (Q1)
/VA8: U2.25 (A8), U5.17 (Q2)
/VA9: U2.24 (A9), U5.16 (Q3)
/VA10: U2.21 (A10), U5.15 (Q4)
/VA11: U2.23 (A11), U5.14 (Q5)
/VA12: U2.2 (A12), U5.13 (Q6)
/VA13: U2.26 (A13), U5.12 (Q7)
/VD0: U1.32 (RD0), U2.11 (Q0), U3.19 (Q0)
/VD1: U1.31 (RD1), U2.12 (Q1), U3.18 (Q1)
/VD2: U1.30 (RD2), U2.13 (Q2), U3.17 (Q2)
/VD3: U1.29 (RD3), U2.15 (Q3), U3.16 (Q3)
/VD4: U1.28 (RD4), U2.16 (Q4), U3.15 (Q4)
/VD5: U1.27 (RD5), U2.17 (Q5), U3.14 (Q5)
/VD6: U1.26 (RD6), U2.18 (Q6), U3.13 (Q6)
/VD7: U1.25 (RD7), U2.19 (Q7), U3.12 (Q7)
/vid: J5.2, Q1.2 (B), R3.1, U1.36 (COMVID)
/~BUSACK: J1.19, J2.19
/~BUSRQ: J1.20, J2.20
/~CAS: U1.2 (~CAS), U6.9
/~CE2: J1.49, J2.49, J3.1
/~CE3: J1.50, J2.50, J3.3
/~CE4: J1.51, J2.51, J3.5
/~CE5: J1.52, J2.52, J3.7
/~CE6: J1.53, J2.53, J3.9
/~CE7: J1.54, J2.54, J3.11
/~CLK: J1.46, J2.46
/~CSR: U1.15 (~CSR), U7.1
/~CSW: U1.14 (~CSW), U7.13
/~CTSA: J1.59, J2.59
/~CTSB: J1.60, J2.60
/~DCDA: J1.57, J2.57
/~DCDB: J1.58, J2.58
/~DTRA: J1.55, J2.55
/~DTRB: J1.56, J2.56
/~HALT: J1.48, J2.48
/~INTI: J1.41, J2.41, U1.16 (~INT)
/~IORQ: J1.42, J2.42
/~M1: J1.43, J2.43
/~MREQ: J1.31, J2.31
/~NMI: J1.47, J2.47
/~RAS: U1.1 (~RAS), U6.11
/~RD: J1.21, J2.21, U7.5
/~RES: J1.32, J2.32, U1.34 (~RESET/SYNC)
/~RFSH: J1.45, J2.45
/~RIA: J1.61, J2.61
/~RIB: J1.62, J2.62
/~RTSA: J1.34, J2.34
/~RTSB: J1.33, J2.33
/~RW: U2.22 (~OE), U3.11 (Cp), U6.12
/~WAIT: J1.44, J2.44
/~WR: J1.22, J2.22, U7.9
GND: C1.2, C2.1, C7.2, C8.2, J1.35, J1.36, J2.35, J2.36, J4.1, R1.2, R3.2, U1.12 (VSS), U2.1 (A14), U2.14 (GND), U2.20 (~CS), U3.10 (GND), U4.1 (OE), U4.10 (GND), U5.1 (OE), U5.10 (GND), U6.1, U6.3, U6.5, U6.7 (GND), U7.7 (GND)
unnamed: C7.1, U1.39 (XTAL1), Y1.1
unnamed: C8.1, U1.40 (XTAL2), Y1.2
unnamed: J3.2, J3.4, J3.6, J3.8, J3.10, J3.12, U7.6, U7.8
unnamed: J4.2, Q1.3 (E), R1.1
unnamed: J5.4, U1.38 (CPUCLK)
unnamed: J5.3, U1.37 (GROMCLK)
unnamed: U7.2, U7.3, U7.4
unnamed: U7.10, U7.11, U7.12

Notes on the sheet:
Default setting: ~{CE2}

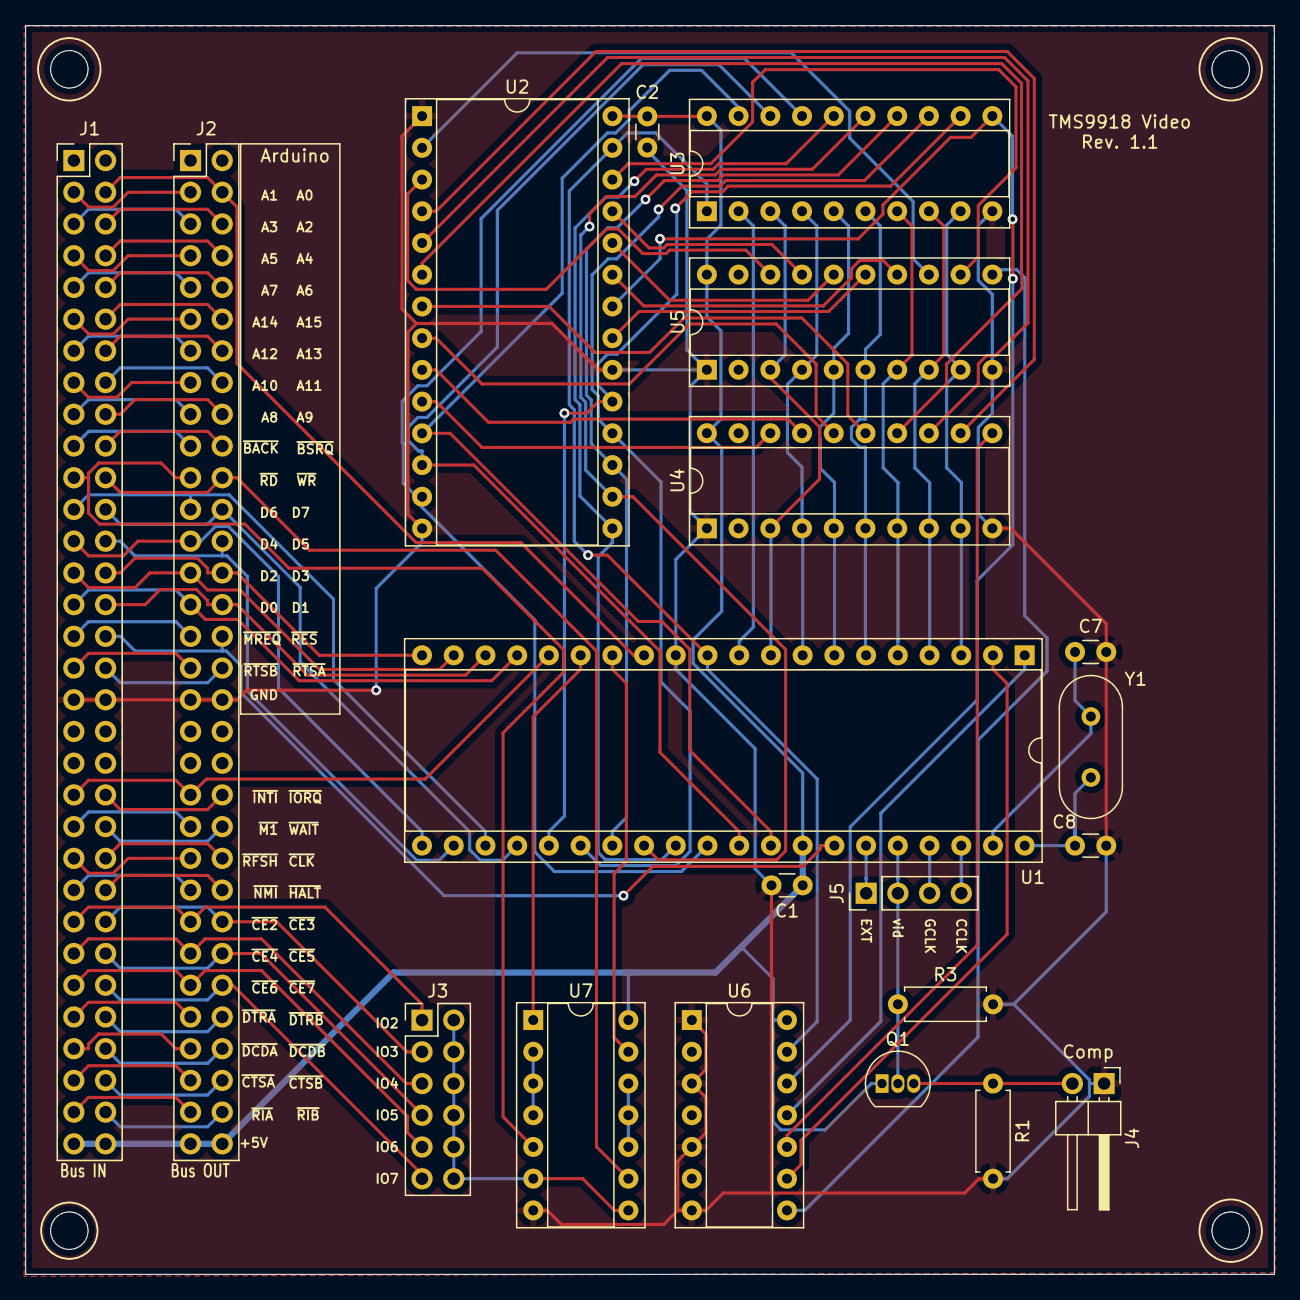
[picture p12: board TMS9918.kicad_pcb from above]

Board: 2 copper layers, 100.0 x 100.0 mm, 20 parts (0 on the bottom side), 104 nets.

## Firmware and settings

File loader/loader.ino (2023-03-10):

/* Copyright (C) 2020  Doctor Volt

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
 You should have received a copy of the GNU General Public License
 along with this program.  If not, see <https://www.gnu.org/licenses/>.
*/
//#include "serdisk.h"
#include "Z80.h"
#include "memory.h"
#include "debug.h"

#define CHUNKLEN 32
#define RTSA 52
#define RTSB 53
#define FS_BASE 0x4000

struct Direntry // https://www.seasip.info/Cpm/format31.html
{
  uint8_t usernum = 0;                                               // User number. 0-15
  char filename[8];                                                  // = {32, 32, 32, 32, 32, 32, 32, 32};               // File name
  char fileext[3];                                                   // = {32, 32, 32};                                    // File extension
  uint8_t EX = 0;                                                    // Extent number, Low byte
  uint8_t S2 = 0;                                                    // Extent number, High byte
  uint8_t S1 = 0;                                                    // Last Record Byte count
  uint8_t RC = 0;                                                    // Number of records (1 record=128 bytes)
  uint8_t AL[16] = {0, 0, 0, 0, 0, 0, 0, 0, 0, 0, 0, 0, 0, 0, 0, 0}; // Allocation. Each AL is the number of a block on the disc
};
Direntry entry;

// Parameter structure for the @ldcpm command
struct Ldaddr
{
  uint16_t base; // Memory address where the image starts
  uint16_t size; // Size of the image
  uint8_t reserved;
  char fname[8];
  char fext[3];
} ldaddr;

void setup()
{
  bus_idle();
  Serial.begin(115200);
  println("Arduino restarted");
  // Check if there is a response on busrequest if not: ZX2020 not connected
  bool connected = true;
  if (BUSRQ(ACTIVE) == BUSERROR)
  {
    connected = false;
  }
  if (BUSRQ(PASSIVE) == BUSERROR)
  {
    connected = false;
  }
  if (!connected)
  {
    println("Not connected to ZX 2020 bus");
    Serial.write("<$>started</$>");
    //delay(10);
    Serial.end();
    return;
  }
  println("ZX 2020 bus connected");
  Serial.write("<$>ready</$>");
}

void serialEvent()
{
  static uint16_t chunkstoload = 0;
  static uint16_t addr; // start addr = BDOS address
  uint8_t chunk[CHUNKLEN];

  Serial.readBytes(chunk, CHUNKLEN);        // Read chunk
  if (chunkstoload == 0)                     // Is it a command from PC? (@...@)
  {                                         // Handle commands
    String command = String((char *)chunk); // Serial.readString();
    //println(command.c_str());
    command = command.substring(command.indexOf("@") + 1, command.indexOf("@", 2)); // .lastIndexOf("@"));
    if (command.equals("load"))
    {
      //  Get start address and total number of bytes expected
      memcpy(&ldaddr, (chunk + 6), sizeof(ldaddr));
      chunkstoload = ceil((float)ldaddr.size / CHUNKLEN);
      addr = ldaddr.base;
      RESET();
      if (BUSRQ(ACTIVE) == BUSERROR)
      {
        println("Loader Error: BUS request failed");
        return;
      }
      if (digitalRead(RTSA) && digitalRead(RTSB))
        println("EEPROM selected");
      else
        println("Warning: Could not select EEPROM. Writing to RAM");

      memProtect(false);
      println("Loading %d chunks (%d bytes). Base: 0x%04X", chunkstoload, chunkstoload*CHUNKLEN, addr);
      Serial.write("<$>rqchunk</$>"); // Signal for loader to send first chunk of image file
      return;
    }
    else if (command.startsWith("start"))
    {
      println("ZX2022 %s",
              command.substring(command.indexOf(":") + 1, command.length()).c_str());
      Serial.write("<$>started</$>");
      RESET();
      bus_idle();
      Serial.end(); // Now the ZX2020 can use the UART0 interface for the serial disk
    }
    else if (command.equals("mkdsk"))
    {
      RESET();
      if (BUSRQ(ACTIVE) == BUSERROR)
      {
        println("Loader Error: BUS request failed");
        return;
      }

      memProtect(false);
      uint8_t *rec_buf = (uint8_t*) malloc(1024);
      memset(rec_buf, 0xE5, 1024);
      memWrite(rec_buf, FS_BASE, 1024);

      if (ldaddr.size) // There is a file: Write record
      {
        String fname = String(ldaddr.fname).substring(0, 8);
        fname.trim();
        println("Writing directory record for file: %s.%s", fname.c_str(), ldaddr.fext);
        memcpy(entry.filename, ldaddr.fname, 8);
        memcpy(entry.fileext, ldaddr.fext, 3);
        entry.RC = (byte)ceil((float)ldaddr.size / 128);
        for (int i = 0; i <= ldaddr.size / 1024; i++)
          entry.AL[i] = i + 1;
        if(!memWrite((uint8_t*)&entry, FS_BASE, 32))
        {
          println("Memory Write Error");
        }
        //hexdump((uint8_t*)&entry,0,32);
      }
      Serial.write("<$>ready</$>");
      memProtect(true);
      println("EE Prom disk written");
    }
    else if (command.startsWith("serdsk"))
    {
      //println("Serial disk ready");
      bus_idle();
      Serial.end();
    }
  }
  else if (chunkstoload) // Is there still data to load into EEPROM?
  {
    if (!memWrite(chunk, addr, CHUNKLEN))
    {
      println("Memory Write Error");
      chunkstoload = 0;
      return;
      Serial.write("<$>error</$>");
    }
    addr += CHUNKLEN;
    chunkstoload--;

    Serial.write("<$>rqchunk</$>"); // Request next chunk
    // println("%d bytes left", bytestoload);
    if (chunkstoload == 0) // All chunks processed
    {
      println("Success");
      memProtect(true);
      Serial.write("<$>ready</$>");
      return;
    }
  }
}

void bus_idle()
{
  DDRA = 0; // Addr Low
  PORTA = 0;
  DDRB = 0; // RTSA, RTSB, RST, MREQ
  PORTB = 0;
  DDRC = 0; // Addr Hi
  PORTC = 0;
  DDRD = 0; // BUSRQ
  PORTD = 0;
  DDRE = 0; // RX0, TX0
  PORTE = 0;
  DDRG = 0; // RD, WR, BUSACK
  PORTG = 0;
  DDRL = 0; // DATA
  PORTL = 0;
}

void loop()
{
}

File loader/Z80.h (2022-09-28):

/* Copyright (C) 2020  Doctor Volt

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
 You should have received a copy of the GNU General Public License
 along with this program.  If not, see <https://www.gnu.org/licenses/>.
*/

#ifndef Z80_H
#define Z80_H

#include <Arduino.h>
// Port B
#define RTSB_PIN PB0 //(Arduino Pin 53) 
#define RTSA_PIN PB1 //(Arduino Pin 52) 
#define MREQ_PIN PB2 //(Arduino Pin 51) Z80 Pin 19
#define RST_PIN PB3 //(Arduino Pin 50) Z80 PIN 26
// Port G
#define RD_PIN PG0   //(Arduino Pin 41) Z80 Pin 21
#define WR_PIN PG1   //(Arduino Pin 40) Z80 Pin 22
#define BUSACK_PIN PG2 //(Arduino Pin 39) Z80 Pin 23
// Port D
#define BUSRQ_PIN PD7  //(Artduino Pin 38) Z80 Pin 25
// Port E
#define TX0_PIN PE0 //(Arduino Pin0 / RX0)
#define TX1_PIN PE1 //(Arduino Pin1 / TX1)
// Address bus
#define ADDR_LO PINA // A0..A7
#define ADDR_HI PINC // A8..A9
#define ADDR ((ADDR_HI << 8) + ADDR_LO)

#define ACTIVE 1  // 0V
#define PASSIVE 0 // 5V, pulled up by 10k resistor

#define BUSERROR 0 //BUSACK failed

inline void RD(uint8_t b)
{
  (b == ACTIVE) ? bitClear(PORTG, RD_PIN) : bitSet(PORTG, RD_PIN);
}
inline void WR(uint8_t b)
{
  (b == ACTIVE) ? bitClear(PORTG, WR_PIN) : bitSet(PORTG, WR_PIN);
}

inline void MREQ(uint8_t b)
{
  (b == ACTIVE) ? bitClear(PORTB, MREQ_PIN) : bitSet(PORTB, MREQ_PIN);
}

inline void BUSALLOC(bool b)
{
  if (b) // Allocate bus
  {
    DDRA = 0xFF; //Addr LO
    DDRC = 0xFF; //Addr HI
    DDRL = 0xFF; //Data
    DDRB |= (1 << MREQ_PIN);
    PORTB |= (1 << MREQ_PIN); //All high (passive)
    DDRG |= (1 << RD_PIN) + (1 << WR_PIN);
    PORTG |= (1 << RD_PIN) + (1 << WR_PIN);
  }
  else // Free bus
  {
    DDRA = 0;
    DDRC = 0;
    DDRL = 0;
    DDRB &= ~((1 << MREQ_PIN) + (1 << RTSA_PIN) + (1 << RTSB_PIN));
    DDRG &= ~((1 << RD_PIN) + (1 << WR_PIN));
  }
}

inline bool BUSRQ(bool b)
{
  b ? bitSet(DDRD, BUSRQ_PIN) : bitClear(DDRD, BUSRQ_PIN);

  //Has Z80 ack'ed the request?
  delay(100);
  if (bitRead(PING, BUSACK_PIN) == b)
  {
    bitClear(DDRD, BUSRQ_PIN); 
    return BUSERROR;
  }

  BUSALLOC(b);
  return 1;
}

inline void RESET(bool b)
{
  b == ACTIVE ? bitSet(DDRB, RST_PIN) : bitClear(DDRB, RST_PIN);
}

inline void RESET()
{
  RESET(ACTIVE);
  delay(100);
  RESET(PASSIVE);
}

#endif

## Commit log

2023-02-12 Board version 1.2
    [zx2022.kicad_pcb, zx2022.kicad_sch]
2023-03-10 Version 1.1
    Bugfixes, SDCC integration
    [loader.ino]

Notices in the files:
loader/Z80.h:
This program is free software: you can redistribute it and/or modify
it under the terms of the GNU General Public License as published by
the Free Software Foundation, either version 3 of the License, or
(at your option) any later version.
